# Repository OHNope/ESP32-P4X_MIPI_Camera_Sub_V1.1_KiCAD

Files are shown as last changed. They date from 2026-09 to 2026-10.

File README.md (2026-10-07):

# ESP32-P4-Function-EV-Board MIPI Camera Sub V1.1 — KiCad

[中文](#中文) | [English](#english)

---

## 中文

这是 Espressif 官方开发板 **ESP32-P4-Function-EV-Board** 的 MIPI 相机转接板（Camera Adapter Board, Camera Sub V1.1, 2024-05-29）的 KiCad 工程。设计版权归 Espressif 所有；本仓库只是把官方 OrCAD/Allegro 设计数据转成 KiCad，并修复了导入过程中出现的问题。

### 官方资料

- 开发板用户指南 (v1.5.2)：<https://docs.espressif.com/projects/esp-dev-kits/en/latest/esp32p4/esp32-p4-function-ev-board/user_guide.html>
- 相机转接板原理图 (PDF)：<https://dl.espressif.com/dl/schematics/esp32-p4-function-ev-board-camera-subboard-schematics.pdf>
- 相机转接板 PCB 布局 (PDF)：<https://dl.espressif.com/dl/schematics/esp32-p4-function-ev-board-camera-subboard-pcb-layout.pdf>
- 官方参考设计包（OrCAD DSN、Allegro BRD、Gerber、BOM、贴片文件）：<https://dl.espressif.com/schematics/CameraAdapterBoardReferenceDesign.zip>

### 为什么需要这个仓库

KiCad 的 OrCAD `.DSN` 导入功能目前只在 Nightly (10.99) 里有，正式版要等到 KiCad 11。即使能导入，解析结果和 Board Setup 的映射也有不少问题，导入后直接跑会有大量 ERC/DRC 报错。本工程逐项修正了这些导入问题，电路连接与官方设计保持一致。

### 打开方式

- **KiCad 10.0 及以上**即可打开（已在 KiCad 10.0.5 正式版和 Nightly 10.99 上验证）。转换和修复是在 Nightly 10.99 里完成的，之后用 KiCad 10.0.5 原生重存为 10.0 格式，以便正式版直接使用，KiCad 11 也能打开。降级前后的网表、焊盘/过孔坐标、坐标文件、Gerber 与钻孔几何、ERC/DRC 结果逐项比对一致。
- 用 KiCad 打开 `SCH_ESP32-P4_FUNCTION_EV_BOARD_MIPI_Camera_Sub_V1.1_20240529.kicad_pro`。
- 符号库 `orcad_import` 和封装库 `Camera_Sub` 都在工程目录内，已通过项目库表 (`sym-lib-table` / `fp-lib-table`) 注册，不依赖任何全局库。

### 检查结果（KiCad 10.0.5 与 Nightly 10.99 `kicad-cli`，结果相同）

| 检查 | 结果 |
| --- | --- |
| ERC | 0 |
| DRC 错误 | 0 |
| 未连接项 | 0 |
| 原理图 / PCB 一致性 | 0 |
| DRC 警告 | 57 条丝印警告，与官方 Gerber 一致（见下文） |

剩余 57 条丝印警告来自原设计本身，已对照官方 Gerber 确认，没有修改：位号字高 0.635 mm 低于 KiCad 默认下限 0.8 mm（33 条）；J1/SW1 的丝印跨过焊盘，生产时由阻焊裁掉（23 条）；"Same-Side FFC" 文字与 R20 丝印相碰（1 条）。

### 修复内容

原理图（OrCAD 导入）：
- 导入器把 OrCAD 的 "Power" 引脚全部映射为 `power_in`，导致 LDO（U1/U2）的 OUT 也成了电源输入，1V8/2V8 无驱动源。已改为 `power_out`。
- 符号库 `orcad_import` 未注册：导出为项目库 `orcad_import.kicad_sym`。
- `Footprint` 字段为空（封装名在 `OrCAD Footprint` 字段中）：已填写为 `Camera_Sub:<封装名>`。
- 3V3/GND 由 J1 从主板引入，添加 PWR_FLAG。
- 4 根 OrCAD 风格的带标签短线一端悬空：截短到标签位置，拓扑不变。
- 工程把原理图图框设为 `empty.kicad_wks`（只画 OrCAD 自带的图框和标题栏），但没有这个文件：KiCad 会退回默认图框，与 OrCAD 标题栏重叠，KiBot 打印原理图时直接报错。已补上空图框文件。

PCB（Allegro 导入）：
- 封装没有库名、Value 和原理图关联：从板上实物封装生成项目封装库 `Camera_Sub.pretty`，补全库名、Value、符号关联和原理图字段。
- 网络名与原理图不一致：标签网络加 `/` 前缀；`Net_xx` 单焊盘网络改为原理图的 `unconnected-(…)` 名称。已逐焊盘与原理图网表核对。
- 两个无位号的 Allegro 机械图形：命名为 MECH1/MECH2 并设为 board-only。
- 约束为 KiCad 默认值：恢复 Allegro 约束（最小线宽 0.127 mm、最小钻孔 0.25 mm）。
- 网络类按实际铜皮分配：`DP_CSI_A_*`（CSI 差分对，0.1778 mm）、`CS_0`（普通信号，0.127 mm）、`POWER`（3V3/AVDD_2V8/DOVDD_1V8/GND，0.635 mm，过孔 0.762/0.5）；预设线宽、过孔和差分对尺寸表填入板上实际使用的尺寸。
- GND 铺铜：间距 0.1778 mm、焊盘实心连接，重新填充。
- 封装的 courtyard 和 Fab 层只是焊盘外框：导入得到的 `Camera_Sub` 封装，F.CrtYd 基本就是焊盘的外接矩形（FFC_24P_0P5 的甚至比焊盘还小），SOT23-5 沿本体长边只有 2.4 mm，比 2.9 mm 的本体还短；F.Fab 要么没有，要么也只是焊盘框。这些形状来自 Espressif 原 Allegro 文件本身：KiCad 把 Allegro 的 place-bound（`PLACE_BOUND_TOP`）原样转成 F.CrtYd、装配外形（`ASSEMBLY_TOP`）转成 F.Fab，而原库的 place-bound 只框住焊盘、不含本体和余量（Allegro 靠封装间距规则控制间距，不靠这个框）。用 KiCad 10.0.5 重新导入官方 BRD，得到的 courtyard/Fab 与本工程首个提交逐个相同，所以不是导入器的问题。这样 KiCad 的 courtyard 重叠检查对这些封装几乎不起作用：在基于本工程的衍生设计里，两颗 SOT-23-5 本体贴在一起 DRC 也没有报错，直到 JLCPCB 贴片审核才发现。已按器件本体重画：F.Fab 画本体外形（IC 和晶振带 1 脚倒角），F.CrtYd 取焊盘和本体各外扩 0.15 mm 的并集，连接器、SOT 和 SW1 用多边形贴合。外扩 0.15 mm 时，两个 courtyard 相接对应 0.3 mm 的本体/焊盘间距，高于 JLCPCB 要求的 0.2 mm；Espressif 原布局仍然没有 courtyard 重叠。本体尺寸：0402 1.0×0.5、0603 1.6×0.8、SOT-23-5 2.9×1.6（ME6211、TI DBV）、SOT-363 2.0×1.25、3225 晶振 3.2×2.5、SW1 4.2×3.4（Espressif BOM）；J1/J2 用 JLCPCB 的 EasyEDA 元件外形（C262721、C2856805），J1 的外形比板边多出约 1.5 mm，与 JLCPCB 贴片预览一致。

### 版权与许可

设计版权归 Espressif Systems (Shanghai) Co., Ltd. 所有。本仓库**不授予任何许可**，详见 [LICENSE](LICENSE)。本仓库为非营利性的学习与参考分享，与 Espressif 无关联、未获其背书；如 Espressif 提出异议，将立即删除。

---

## English

KiCad project for the MIPI Camera Adapter Board (Camera Sub V1.1, 2024-05-29) of Espressif's **ESP32-P4-Function-EV-Board**. The design is copyright Espressif. This repository only converts Espressif's OrCAD/Allegro design data to KiCad and fixes the problems introduced by the import.

### Official resources

- Board user guide (v1.5.2): <https://docs.espressif.com/projects/esp-dev-kits/en/latest/esp32p4/esp32-p4-function-ev-board/user_guide.html>
- Camera adapter board schematic (PDF): <https://dl.espressif.com/dl/schematics/esp32-p4-function-ev-board-camera-subboard-schematics.pdf>
- Camera adapter board PCB layout (PDF): <https://dl.espressif.com/dl/schematics/esp32-p4-function-ev-board-camera-subboard-pcb-layout.pdf>
- Official reference design package (OrCAD DSN, Allegro BRD, Gerbers, BOM, placement): <https://dl.espressif.com/schematics/CameraAdapterBoardReferenceDesign.zip>

### Why

KiCad's OrCAD `.DSN` importer is currently only in the Nightly builds (10.99) and will ship in KiCad 11. Even then, the parser and the Board Setup mapping get a lot wrong, and a fresh import reports many ERC/DRC errors. This project fixes those import problems one by one. The connectivity matches the official design.

### Opening the project

- **Opens in KiCad 10.0 or later** (verified on KiCad 10.0.5 stable and Nightly 10.99). The conversion and fixes were done in Nightly 10.99, then the files were re-saved natively by KiCad 10.0.5 in the 10.0 format so the stable release can use them; KiCad 11 will open them too. Netlist, pad/via coordinates, placement file, Gerber and drill geometry and ERC/DRC results were compared before and after the downgrade and match.
- Open `SCH_ESP32-P4_FUNCTION_EV_BOARD_MIPI_Camera_Sub_V1.1_20240529.kicad_pro`.
- The `orcad_import` symbol library and the `Camera_Sub` footprint library live in the project folder and are registered in the project library tables. No global libraries are needed.

### Check results (KiCad 10.0.5 and Nightly 10.99 `kicad-cli`, identical)

| Check | Result |
| --- | --- |
| ERC | 0 |
| DRC errors | 0 |
| Unconnected items | 0 |
| Schematic / PCB parity | 0 |
| DRC warnings | 57 silkscreen warnings, same as Espressif's Gerbers (see below) |

The 57 remaining silkscreen warnings come from the original design and were checked against Espressif's Gerbers: 0.635 mm reference text, below KiCad's default 0.8 mm minimum (33); J1/SW1 silkscreen crossing pads, clipped by the solder mask at fabrication (23); the "Same-Side FFC" text touching R20's silkscreen (1).

### What was fixed

Schematic (OrCAD import):
- The importer maps every OrCAD "Power" pin to `power_in`, so the LDO (U1/U2) OUT pins became inputs and 1V8/2V8 had no driver. Changed to `power_out`.
- The `orcad_import` symbol library was not registered: exported to the project library `orcad_import.kicad_sym`.
- Empty `Footprint` fields (the package name was in `OrCAD Footprint`): set to `Camera_Sub:<package>`.
- PWR_FLAGs added on 3V3/GND, which enter from the main board through J1.
- Four OrCAD-style labelled stub wires had a dangling end: trimmed to the label, topology unchanged.
- The project sets the schematic drawing sheet to `empty.kicad_wks` (so only the OrCAD frame and title block are drawn), but the file was missing: KiCad fell back to its default sheet, drawn over the OrCAD title block, and KiBot stops when printing the schematic. Added the empty drawing sheet.

PCB (Allegro import):
- Footprints had no library ID, value or symbol link: generated the project footprint library `Camera_Sub.pretty` from the placed footprints and filled in the library IDs, values, symbol links and schematic fields.
- Net names did not match the schematic: label nets now carry the `/` prefix and single-pad `Net_xx` nets use the schematic's `unconnected-(…)` names. Checked pad by pad against the schematic netlist.
- Two unreferenced Allegro drawing symbols are named MECH1/MECH2 and set to board-only.
- Constraints were KiCad defaults: restored the Allegro values (0.127 mm minimum track, 0.25 mm minimum drill).
- Netclasses assigned from the routed copper: `DP_CSI_A_*` (CSI differential pairs, 0.1778 mm), `CS_0` (ordinary signals, 0.127 mm), `POWER` (3V3/AVDD_2V8/DOVDD_1V8/GND, 0.635 mm, 0.762/0.5 vias). The pre-defined track, via and differential-pair size tables hold the sizes used on the board.
- GND pour: 0.1778 mm clearance with solid pad connection, refilled.
- Footprint courtyards and Fab outlines only traced the pads: in the imported `Camera_Sub` footprints, F.CrtYd was essentially the pads' bounding box (smaller than the pads on FFC_24P_0P5), so SOT23-5's courtyard was 2.4 mm along the body, shorter than its 2.9 mm body; F.Fab was missing or also just the pad box. These shapes come from Espressif's Allegro file itself: KiCad converts Allegro place-bounds (`PLACE_BOUND_TOP`) to F.CrtYd and assembly outlines (`ASSEMBLY_TOP`) to F.Fab as they are, and the original library's place-bounds only enclose the pads, with no body and no margin (Allegro keeps parts apart with package-to-package spacing rules, not with this outline). A fresh import of the official BRD in KiCad 10.0.5 gives the same courtyards and Fab outlines as this repository's first commit, so the importer is not at fault. KiCad's courtyard-overlap check therefore hardly worked for these footprints: in a design derived from this project, two SOT-23-5 bodies touched without any DRC error, and JLCPCB's assembly review caught it. Redrawn from the component bodies: F.Fab is the body outline (with a pin-1 chamfer on the ICs and the crystal), and F.CrtYd is the union of the pads and the body, each grown by 0.15 mm, drawn as a polygon on the connectors, the SOT packages and SW1. With 0.15 mm, touching courtyards mean 0.3 mm between bodies or pads, above JLCPCB's 0.2 mm minimum, and Espressif's own placement still has no courtyard overlap. Body sizes: 0402 1.0×0.5, 0603 1.6×0.8, SOT-23-5 2.9×1.6 (ME6211, TI DBV), SOT-363 2.0×1.25, 3225 crystal 3.2×2.5, SW1 4.2×3.4 (Espressif BOM); J1/J2 use JLCPCB's EasyEDA component outlines (C262721, C2856805). J1's outline reaches about 1.5 mm past the board edge, as in JLCPCB's assembly preview.

### Copyright and license

The design is copyright Espressif Systems (Shanghai) Co., Ltd. This repository **grants no license**; see [LICENSE](LICENSE). It is a non-commercial share for study and reference, is not affiliated with or endorsed by Espressif, and will be taken down if Espressif objects.

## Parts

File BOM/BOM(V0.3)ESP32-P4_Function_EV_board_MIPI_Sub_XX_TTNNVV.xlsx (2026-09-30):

BOM(V0.3)_ESP32-P4_Function_EV_board_MIPI_Sub_XX_TTNNVV
Item Number | Quantity | Part Reference | Value | PCB Footprint | Description | Manufacturer | Manufacturer Part # | 备注
1 | 4 | C1,C4,C6,C8 | 10uF/6.3V(20%) | C0603 | MLCC
2 | 6 | C2,C5,C7,C9,C11,C15 | 0.1uF/50V(10%) | C0402 | MLCC
3 | 1 | C3 | 1uF/25V(10%) | C0402 | MLCC
4 | 1 | C10 | 1nF/50V(10%) | C0402 | MLCC
8 | 1 | J1 | FPC_15P_R | FFC_15P_1_MIPI_R | FFC连接器，间距1mm，15P，抽屉式下接 | 钜硕电子 | AFA07-S15FCA-00 | 参考：嘉立创C262721
9 | 1 | J2 | FPC_24P | FFC_24P_0P5 | FFC连接器，间距0.5mm，24P，翻盖式下接 | 讯普 | FPC-05F-24PH20 | 参考：嘉立创C2856805
10 | 1 | Q3 | DUAL_NMOS | SOT-363 | 双NMOS，耐压30V，电流220mA，阈值电压MAX1.5V | DIODES | DMN63D8LDW-7 | 注意阈值电压最大值小于1.8V
 |  |  |  |  |  | LRC | LBSS138DW1T1G
11 | 6 | R10,R11,R14,R15,R18,R19 | 10K(1%) | R0402 | Resistor
12 | 2 | R20,R23 | 2.2K(1%) | R0402 | Resistor
13 | 1 | SW1 | NTC013-AT1J-A160T | SW4-4P2X3P2X2P5-SMT | 4.2*3.4*2.5mm立贴,轻触开关 | 怡远 | YTS-A016-2 | 参考：嘉立创C2910673
14 | 1 | U1 | ME6211C18M5G-N | SOT23-5 | LDO | 微盟 | ME6211C18M5G-N | 参考：嘉立创C236671
15 | 1 | U2 | ME6211C28M5G-N | SOT23-5 | LDO | 微盟 | ME6211C28M5G-N | 参考：嘉立创C53099
16 | 1 | Y1 | 24MHz | XTAL3225 | 24MHz有源晶振 1.8V-3.3V ±10ppm | MDH | 2.1.3.2400037
17 | 1 | - | - | - | ESP32-P4_FUNCTION_EV_BOARD_MIPI_Sub_V1.1, 4L, 32.0*24.0*1.6mm, 哑光黑色阻焊, 白色字符, 无铅喷锡，含阻抗管控。 | - | - | -

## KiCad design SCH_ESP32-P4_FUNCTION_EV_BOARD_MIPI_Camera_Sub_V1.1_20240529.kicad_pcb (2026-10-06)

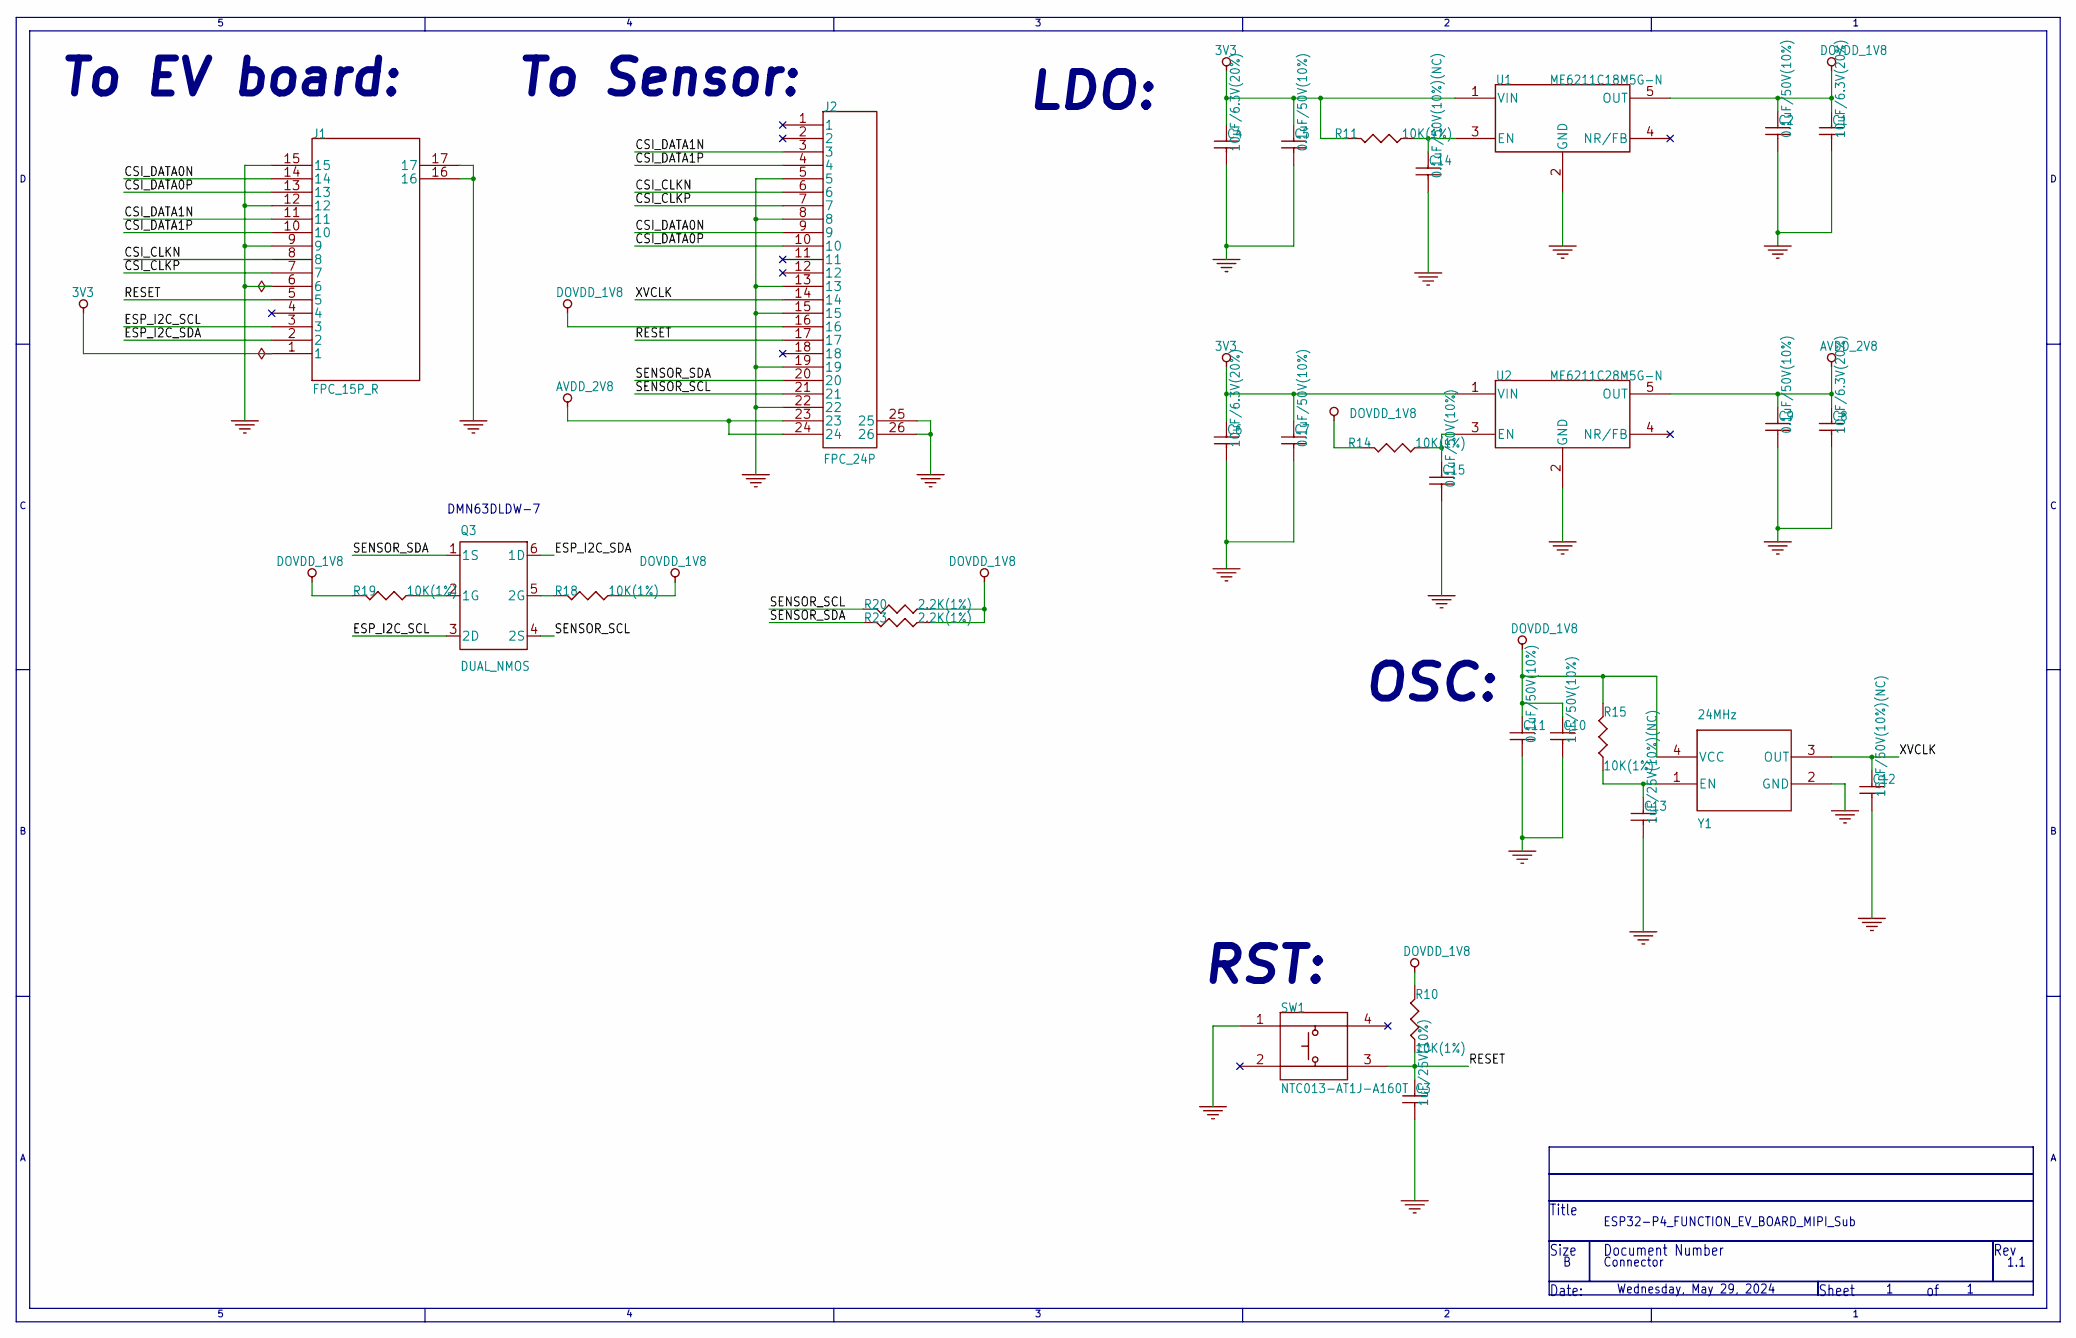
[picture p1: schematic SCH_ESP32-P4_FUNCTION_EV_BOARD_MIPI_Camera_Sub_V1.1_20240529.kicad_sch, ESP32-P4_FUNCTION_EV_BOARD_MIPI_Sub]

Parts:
C1, C4, C6, C8: 10uF/6.3V(20%); C0603
C2, C5, C7, C9, C11, C15: 0.1uF/50V(10%); C0402; Part Number ES110451066200
C3: 1uF/25V(10%); C0402; Part Number ES110451066200
C10: 1nF/50V(10%); C0402; Part Number ES110451066200
C12: 15pF/50V(10%)(NC); C0402; Part Number ES110451066200
C13: 1uF/25V(10%)(NC); C0402; Part Number ES110451066200
C14: 0.1uF/50V(10%)(NC); C0402; Part Number ES110451066200
J1: FPC_15P_R; FFC_15P_1_MIPI_R
J2: FPC_24P; FFC_24P_0P5
Q3: DUAL_NMOS; SOT-363
R10, R11, R14, R15, R18, R19: 10K(1%); R0402; Part Number ES210400000000
R20, R23: 2.2K(1%); R0402; Part Number ES210400000000
SW1: NTC013-AT1J-A160T; SW4-4P2X3P2X2P5-SMT; Part Number ES511600400000
U1: ME6211C18M5G-N; SOT23-5; Part Number ES41140207000000
U2: ME6211C28M5G-N; SOT23-5; Part Number ES41140207000000
Y1: 24MHz; XTAL3225

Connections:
3V3: C4.1, C5.1, C6.1, C7.1, J1.1, R11.2, U1.1 (VIN), U2.1 (VIN)
/CSI_CLKN: J1.8, J2.6
/CSI_CLKP: J1.7, J2.7
/CSI_DATA0N: J1.14, J2.9
/CSI_DATA0P: J1.13, J2.10
/CSI_DATA1N: J1.11, J2.3
/CSI_DATA1P: J1.10, J2.4
/ESP_I2C_SCL: J1.3, Q3.3 (2D)
/ESP_I2C_SDA: J1.2, Q3.6 (1D)
/RESET: C3.1, J1.5, J2.17, R10.1, SW1.3
/SENSOR_SCL: J2.21, Q3.4 (2S), R20.2
/SENSOR_SDA: J2.20, Q3.1 (1S), R23.2
/XVCLK: C12.1, J2.14, Y1.3 (OUT)
AVDD_2V8: C8.1, C9.1, J2.23, J2.24, U2.5 (OUT)
DOVDD_1V8: C1.1, C2.1, C10.1, C11.1, J2.16, R10.2, R14.2, R15.2, R18.1, R19.2, R20.1, R23.1, U1.5 (OUT), Y1.4 (VCC)
GND: C1.2, C2.2, C3.2, C4.2, C5.2, C6.2, C7.2, C8.2, C9.2, C10.2, C11.2, C12.2, C13.2, C14.2, C15.2, J1.6, J1.9, J1.12, J1.15, J1.16, J1.17, J2.5, J2.8, J2.13, J2.15, J2.19, J2.22, J2.25, J2.26, SW1.1, U1.2 (GND), U2.2 (GND), Y1.2 (GND)
unnamed: Q3.2 (1G), R19.1
unnamed: Q3.5 (2G), R18.2
unnamed: C14.1, R11.1, U1.3 (EN)
unnamed: C15.1, R14.1, U2.3 (EN)
unnamed: C13.1, R15.1, Y1.1 (EN)

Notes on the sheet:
OSC:
Size
DMN63DLDW-7
Connector
1.1
RST:
Document Number
Wednesday, May 29, 2024
Rev
LDO:
Sheet
ESP32-P4_FUNCTION_EV_BOARD_MIPI_Sub
Title
To EV board:
Date:
To Sensor:

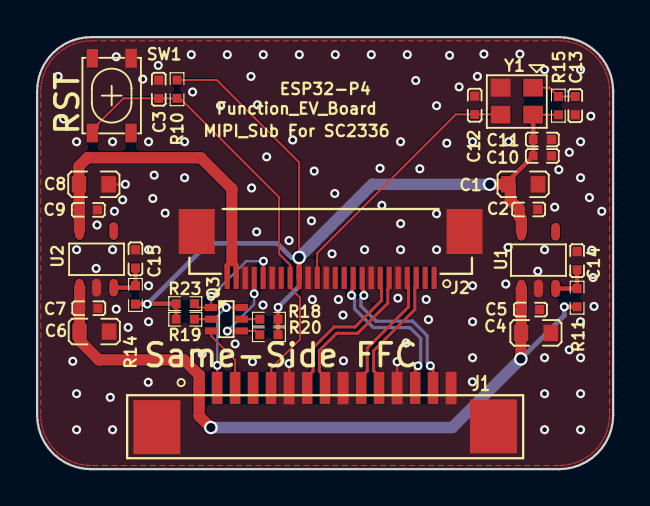
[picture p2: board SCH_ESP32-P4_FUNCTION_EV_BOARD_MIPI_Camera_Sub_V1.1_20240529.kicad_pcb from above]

Board: 4 copper layers, 32.0 x 24.0 mm, 32 parts (0 on the bottom side), 21 nets.

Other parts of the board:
MECH1, MECH2: (no value)

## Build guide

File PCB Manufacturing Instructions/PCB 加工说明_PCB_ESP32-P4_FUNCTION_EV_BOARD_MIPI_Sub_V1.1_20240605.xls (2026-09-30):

PCB加工工艺要求说明书 PCB Fabrication Requirements |  |  |  |  |  |  |  |  |  |  | I. 板料及叠层(请按设计来，PP型号如有更换，请邮件通知。) Material and Stackup (Please follow the design. If the PP model is changed, please inform us via e-mail.)
文件名： File Name: |  | ESP32-P4_FUNCTION_EV_BOARD_MIPI_Sub |  | 版本号： Version: |  | V1.1 | 物料名称： Material: | PCB
PCB 加工要求： PCB Processing Requirements:
 |  |  |  |  |  |  | 附图 Attachment
 | 1.数 量： Order Quantity： |  | TBD | 块 PCS |  |  | 12.交货日期： Delivery Date:
 | 2.层 数： Number of Layers:
 | 3.尺 寸： Dimension： |  | 32 |  | mm | 24 | mm |  | 详见 Gerber 文件尺寸 Refer to the Gerber file
 | 4.板 厚： Board Thickness：
 | 5.材 料： Material Type： |  |  |  | 其他材料： Other Material：
 | 6.铜箔厚度： Copper Thickness： |  | 内层 Inner-Layer |  | 外层 Outer-Layer |  | 13.表面涂层： Surface Finishing： |  |  |  | II. 下图所示高亮的走线需做阻抗控制。 Please do impedance control for trace that highlights in the image below.
 | 7.阻 焊： Solder Mask: |  |  |  | 颜 色： Color: |  | 14.加工厂商标记： Manufacturer's Marking：
 | 8.字 符： Silkscreen: |  |  |  | 颜 色： Color: |  | UL 标记 UL Marking |  |  |  | 1.下图 TOP & BOTTOM 层高亮紫色的走线需要做差分 100 欧姆阻抗控制。
 | 9.过孔处理方式： Through hole processing： |  |  |  |  |  | 制作日期 Manufature Date
 | 10.测 试： Test：
 | 11.设计软件及其版本： Software Version: |  |  | Allegro 16.6
 | 15.交货方式： Delivery Type： |  |  |  | 单元/片 Unit/PCS | 拼板交货允许报废 Panelization allows scrap |  |  |  | PCS/SET
 | 16.其 他： Others:
 | 17.层次排列： Layer Sequence： |  | L1_TOP, L2_GND, L3_POWER, L4_BOTTOM
 | 说明(Notes)：
 | 1.右图高亮的 RF 走线需要做 50 欧姆阻抗控制。请邮件说明实际制版的层压图及阻抗报告。 Please do 50ohm impedance control for RF trace that highlights in the image right. Please send us the actual laminate structure that you use and the information of impedance control.
 | 2.两面盖油的双面塞孔，单面开窗的半塞孔，双面开窗的过孔不塞孔。 Double-sided plug hole with oil cover on both sides, half-plug hole with open window on one side，non-plug hole with double-side window.
 | 3.如拼版,切割边磨平不能有毛刺。 Sharp edges should be avoided in case of multi panel.
 | 4.如存在金手指或是 socket，需要进行镀硬金处理。并注意焊接时焊盘不可沾锡。 If there exists gold finger or socket, hard gold plating is needed. Besides, soldering tin should be avoided on the pad.
 | 其他特殊说明：按照 PCB 文件加工，并请注意按照上面的技术要求。
 | Other special specification: please fabricate based on the PCB file and pay attention to the above technical requirements.
 | 加工工艺要求如下:
 | A. 沉金厚：金厚：半孔板 min 0.03um，非半孔板 min 0.0254um；镍厚按 min 2.54 um；
 | 测试沉金厚度面积为 2 - 10 平方 mm 的区域，连续测 10 次的平均值！
 | B. PTH 孔：±0.075 mm ；NPTH 孔：±0.05 mm；PTH 槽孔 ±5 mil；
 | C. 孔铜:通孔：15 um (min)；
 | D. 外形公差：±0.10 mm；
 | E. 板曲：≤ 0.75%；
 | F. 板厚公差：1 mm 以下公差： ±0.1 mm ； 1 mm 及以上公差： ±10%；
 | G. 阻焊油墨：10 - 40 um；
 | H. BGA & SMD：公差：±20%； 线宽 ＜ 4 mil 公差: ±1 mil, ≥ 4mil 公差：±20%；
 | I. 孔到边公差：±0.1 mm，孔到孔公差：±0.075 mm；
 | J. 内直角及小于 R 0.5 mm 的内角按 R 0.5 mm 制作；
 | K. 其他标准，按照 IPC-A-600 CLASS II 执行。

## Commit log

2026-09-30 ESP32-P4-Function-EV-Board MIPI Camera Sub V1.1 KiCad project
    KiCad conversion of Espressif's official Camera Adapter Board reference
    design (https://dl.espressif.com/schematics/CameraAdapterBoardReferenceDesign.zip),
    with the OrCAD/Allegro import problems fixed: LDO output pin type, project
    symbol/footprint libraries, footprint links and net names, and Allegro
    design constraints. ERC 0, DRC 0 errors.
    Converted and fixed in KiCad Nightly 10.99, then saved in the KiCad 10.0
    format so the project opens in KiCad 10.0.x stable (and KiCad 11). The
    10.0 files match the 10.99 ones: identical netlist, pad/via coordinates,
    placement, Gerber/drill geometry and ERC/DRC results.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
    [BOM(V0.3)ESP32-P4_Function_EV_board_MIPI_Sub_XX_TTNNVV.xlsx, PCB 加工说明_PCB_ESP32-P4_FUNCTION_EV_BOARD_MIPI_Sub_V1.1_20240605.xls, SCH_ESP32-P4_FUNCTION_EV_BOARD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]
2026-09-30 Replace embedded TIFF image with lossless PNG
    The title-block image imported from OrCAD was a TIFF with Photoshop/IPTC
    tags that libtiff rejects, so KiCad showed a warning dialog on open.
    Re-encoded as PNG (pixel-identical) and adjusted its scale so the
    rendered size is unchanged.
    [SCH_ESP32-P4_FUNCTION_EV_BOARD_MIPI_Camera_Sub_V1.1_20240529.kicad_sch]
2026-09-30 Assign netclasses and fill pre-defined sizes from routed copper
    - CS_0 for ordinary signals (0.127 mm), new POWER class for 3V3,
    AVDD_2V8, DOVDD_1V8 and GND (0.635 mm, 0.762/0.5 via), DP_CSI_A_*
    for the CSI pairs; nets assigned explicitly by name.
    - Default class and via sizes match the board (0.127 mm, 0.508/0.254).
    - Drop the unused CS_1 class (identical to the DP_CSI_A_* classes).
    - Fill pre-defined track, via and diff-pair size tables.
2026-09-30 Re-apply netclasses and pre-defined sizes on KiCad 10.0 project file
    KiCad 10.0.5 had the project open and rewrote the .kicad_pro from its
    in-memory settings, reverting the previous change. Re-apply the
    netclasses, net assignments and size tables on top of the 10.0-written
    project file.
2026-09-30 Re-save project file from KiCad 10.0 (formatting only)
2026-10-02 Add the empty drawing sheet the project already references
    The OrCAD import set the schematic drawing sheet to empty.kicad_wks so that
    only the OrCAD frame and title block are drawn, but the file was never
    committed. KiCad fell back to its default sheet, drawn over the OrCAD title
    block, and KiBot stops printing the schematic with "Missing
    empty.kicad_wks worksheet". ERC, DRC and netlists are unaffected.
2026-10-06 Redraw footprint courtyards and Fab outlines from the component bodies
    The imported Camera_Sub footprints had courtyards that only traced the
    pads (SOT23-5 was 2.4 mm along a 2.9 mm body, FFC_24P_0P5 smaller than
    its own pads) and Fab outlines that were missing or also pad boxes, so
    KiCad's courtyard-overlap check could not catch touching bodies. A
    derived design placed two SOT-23-5 bodies against each other without a
    DRC error and JLCPCB's assembly review rejected it.
    F.Fab is now the body outline and F.CrtYd the union of pads and body,
    each grown by 0.15 mm. Board instances are updated to match the library;
    placement, copper and fabrication outputs are unchanged. DRC: 0 errors,
    0 unconnec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
    [SCH_ESP32-P4_FUNCTION_EV_BOARD_MIPI_Camera_Sub_V1.1_20240529.kicad_pcb]
2026-10-07 README: trace the pad-only courtyards to Espressif's place-bounds
    A fresh import of the official BRD in KiCad 10.0.5 gives the same
    courtyard and Fab geometry as the first commit: the importer maps
    PLACE_BOUND_TOP and ASSEMBLY_TOP as they are, and the original library's
    place-bounds only enclose the pads.
